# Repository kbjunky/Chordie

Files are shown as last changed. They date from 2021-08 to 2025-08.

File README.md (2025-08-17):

# **This project is deprecated, check back soon for an updated version of Chordie** #
# **Chordie**
## **A chording keyboard you shouldn't be scared of**

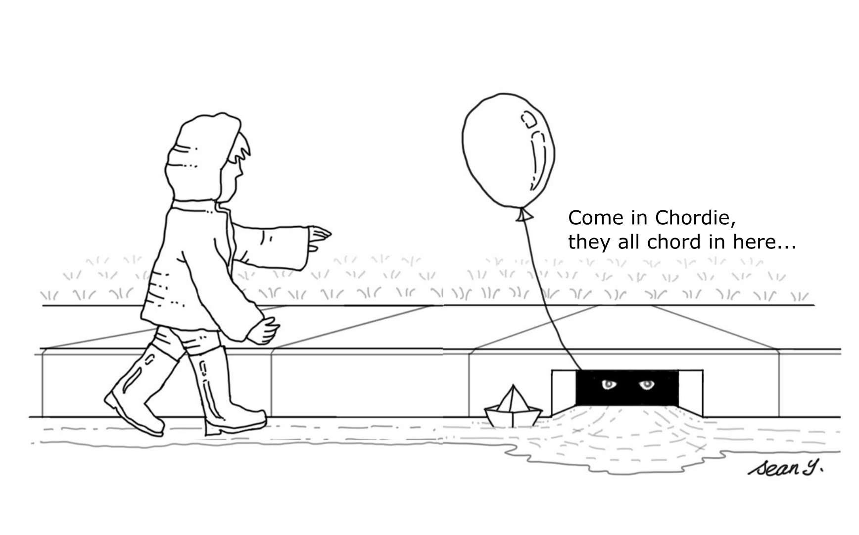
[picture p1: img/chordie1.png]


***Chordie "It" inspired picture courtesy of [Sean Yin](https://www.coroflot.com/sean_yin)***



### Chordie is a chording keyboard heavily inspired by [gBoards' Ginny keyboard](https://www.gboards.ca/product/ginni) running on awesome chording engine by [DennyTom](https://github.com/DennyTom/qmk_firmware/tree/feature/buttery_engine_v2/users/dennytom/chording_engine). It supports all 104 keys found on normal keyboards and much more in large part thanks to [ASETNIOP](http://asetniop.com/) layout. For a complete experience it's also equipped with trackball. Except for the mouse sensor module whole assembly can be handwired in about 6 hours.

## **BOM**
|Item |Count  |Example|
|:--- |:---:  |:---:|
|MCP23017 I2C Expander Breakout Board |2 |[Link](https://www.aliexpress.com/item/1005002491319987.html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)|
|Pro Micro 5V 16MHz |1 |[Link](https://www.aliexpress.com/item/32768308647.html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)|
|TRRS Socket PJ-320A |2 |[Link](https://www.aliexpress.com/item/4000661212458.html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)|
|TRRS Cable Male to Male 0.5m |1 |[Link](https://www.aliexpress.com/item/32905903526.html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)|
|Enameled copper wire 0.2mm 10m |1 |[Link](https://www.aliexpress.com/item/1005003799096513.html?spm=a2g0o.order_list.order_list_main.26.21ef18020rLkLI)|
|5mm kapton tape |1 |[Link](https://www.aliexpress.com/item/4000808659339.html?spm=a2g0o.order_list.order_list_main.86.21ef18020rLkLI)|
|EVQ-WGD001 encoder with switch |1 |[Link](https://www.aliexpress.com/item/4001293888953.html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)|
|Kailh Choc V1 25g or 20g MX switch |16 |[Link](https://www.aliexpress.com/item/4000907409650.html?spm=a2g0o.store_pc_groupList.8148356.11.606939a66Tvk6L)|
|Choc/MX keycaps 1u |10 |[Link](https://www.aliexpress.com/item/32979973961.html?spm=a2g0o.store_pc_groupList.8148356.21.1b9d36a4Coe1f0)|
|Choc/MX keycaps 1.5u |6 |[Link](https://www.aliexpress.com/item/4000135705283.html?spm=a2g0o.store_pc_groupList.8148356.31.5b1136a4d8gvZK)|
|8mm x 1mm antislip pads |14 |[Link](https://www.aliexpress.com/item/32767105328.html?spm=a2g0o.order_list.order_list_main.5.4f631802SBcIju)|
|ZrO2 bearing ball |3 |[Link](https://www.aliexpress.com/item/4000829132124.html?spm=a2g0o.order_list.order_list_main.24.649218029s2nlG)|
|M570/Ergo 34mm trackball ball |1 |[Link](https://www.aliexpress.com/item/1005003007477853.html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)|
|M2x3mm heat insert (optional) |15 |[Link](https://www.aliexpress.com/item/33021847966.html?spm=a2g0o.order_detail.order_detail_item.9.62d2f19cZBgXLP)
|M2x15mm screw (trackball) |3 |[Link](https://www.aliexpress.com/item/32973784147.html?spm=a2g0o.order_detail.order_detail_item.3.28ecf19cnWSpWO)
|M2x4mm screw |12 |[Link](https://www.aliexpress.com/item/32973784147.html?spm=a2g0o.order_detail.order_detail_item.3.28ecf19cnWSpWO)
|PMW3360 sensor module |1 |[Link](https://github.com/kbjunky/PMW3360) \| [Link](https://www.aliexpress.com/item/1005007729769668.html?spm=a2g0o.order_list.order_list_main.55.649218029s2nlG)

## **IrDA** ***(optional)***
|Item |Count  |Example|
|:--- |:---:  |:---:|
|TCRT5000 sensor |2 |[Link](https://www.aliexpress.com/item/32841920225.html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)|
|680/10k Ohm resistor |2 each |[Link](https://www.aliexpress.com/item/32847096736.html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)

## **Tools**
|Item |Count  |Example|
|:--- |:---:  |:---:|
|Soldering iron 80W |1 |[Link](https://www.aliexpress.com/item/4000005873814.html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)|
|Tin wire 0.5 to 1mm will do |1 |[Link](https://www.aliexpress.com/item/32946643268.html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)|
|Hot glue gun (optional) |1 |[Link](https://www.aliexpress.com/item/1005001393578323.html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)|
|Solder flux/paste |1 |[Link](https://www.aliexpress.com/item/32948598235.html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)
|Digital multimeter with diode test |1 |[Link](https://www.aliexpress.com/item/1005004951791846.html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)

## **Remarks**
*   You can buy a bundle that is soldering iron + tin wire + some other accessories that you think might come usefull. Buying a bundle with a multimeter is a good idea.
*   Better kecaps are [MKUltra](https://mkultra.click/mbk-choc-keycaps).
*   For MX switches any linear switch can be swapped with 20g spring.
*   TRRS cable can be L shaped only on the left side due to the trackball blocking the way on the right side.
*   Solder flux helps with melting isolation on the enameled wire. Just put some where you need to melt the isolation and it should melt quickier.
*   Multimeter (continuity tester) is a must and comes handy when testing if every wire is connected properly.
*   Using heat inserts is recommended.

# **Build guide**

## **Chordie OpenSCAD generator**
Chordie comes with OpenSCAD generator that allows for easy cutomization of:
*   Height of switch/encoder columns.
*   Use of heat inserts or just screws.
*   I2C expander mounting hole dimensions as well as having expander exposed/covered.
*   Choc/MX type sockets.
*   IR sensor.
*   Custom tolerance of switch/encoder sockets.

How to customize your Chordie:
*   Download and install [OpenSCAD](https://openscad.org/).
*   Open ***config.scad*** from generator folder of this repository with OpenSCAD.
*   Adjust settings following tips from the config file.
*   When ready to print hit 'Render' (F6) and then ***File->Export to STL***.
*   Tip: Encoder (ENC) column should be a bit higher than (FF) column. Also thumb keys should be a bit higher than the rest. But this is mostly my preference. 
*   Tip: When measuring I2C expander boards provide exact value into the config file. Proper margin will be added by default.



## **3D printing**
Recommended settings:
*   Material: any, preferably PLA/PETG
*   Layer height 0.2mm
*   Infill >=15%
*   Supports are needed under audio jack holes and on the trackball where MCU USB socket is placed.

## **Wiring**
Before you start make sure your Chordie suits your hands well. Play with it for a while with just switches placed into the sockets. Wiring takes some time and last thing you want to do is to start over because some part isn't properly setup. For example you might find out that encoder is too low etc. Check if canals for the wires aren't filled with plastic. Check if all parts (switches/audio jacks/encoder/I2C exapanders etc.) fit into their sockets.

**While routing check every connection with continuity meter!**

**If you're using heat inserts start with them. Once done try if the bottom plate fits etc.**
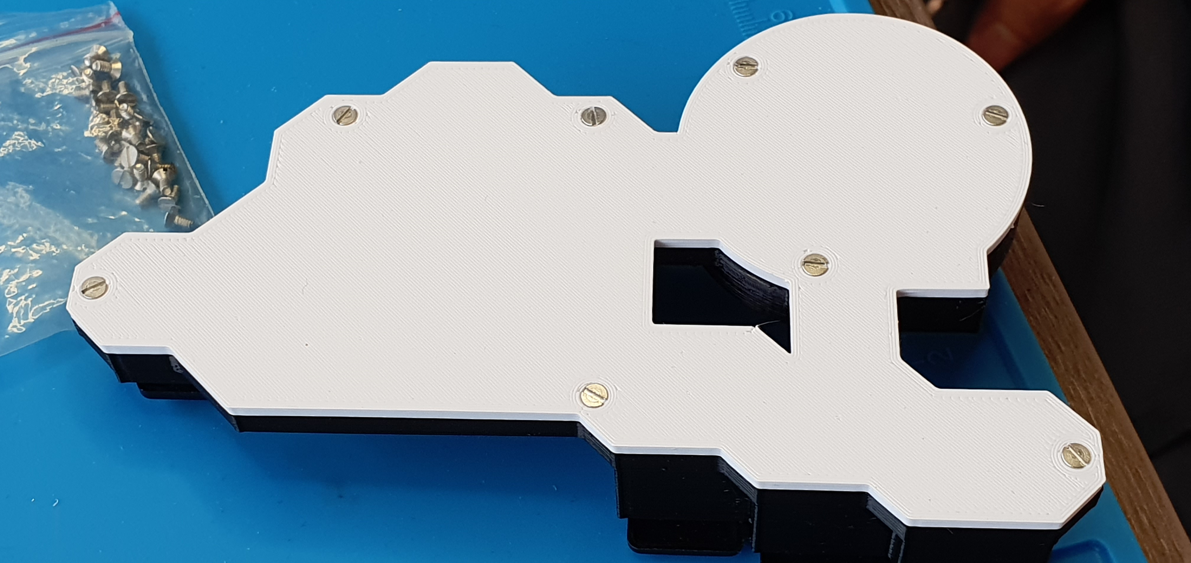
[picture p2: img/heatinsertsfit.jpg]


Attach kepton tape to the bottom side of ProMicro and top side of I2C expanders(cover the pads). This way you will avoid tin blobs.


Setup the address pins on I2C expanders following the diagram.

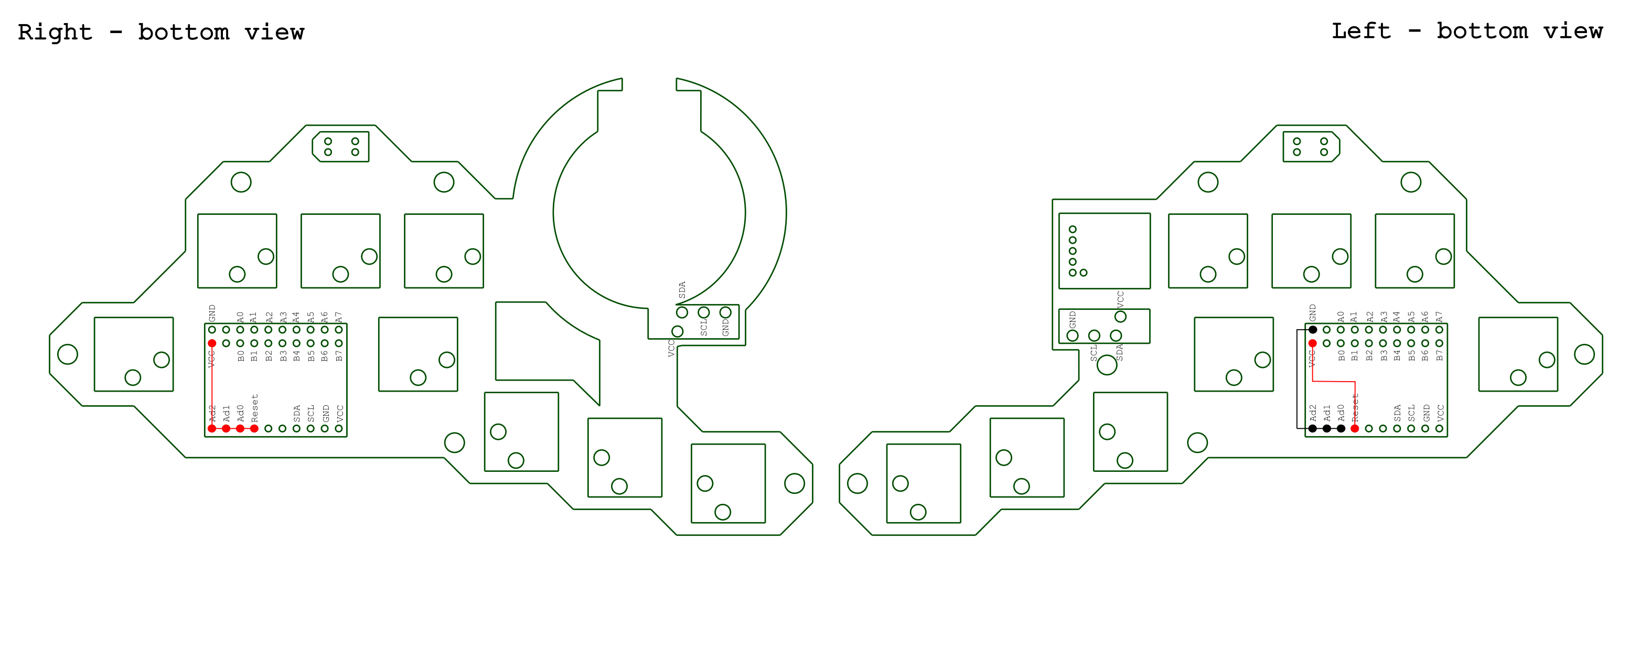
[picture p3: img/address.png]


It should look something like this.



Next you will have to prepare the switches. Put some tin on every switch pin then place the switches into the sockets. Make sure pins are facing the same way as on the photo/diagram. At this point you can also attach the I2C expander. Use small amount of hot glue to lock it in place. Be sure not to cover any of the pads.

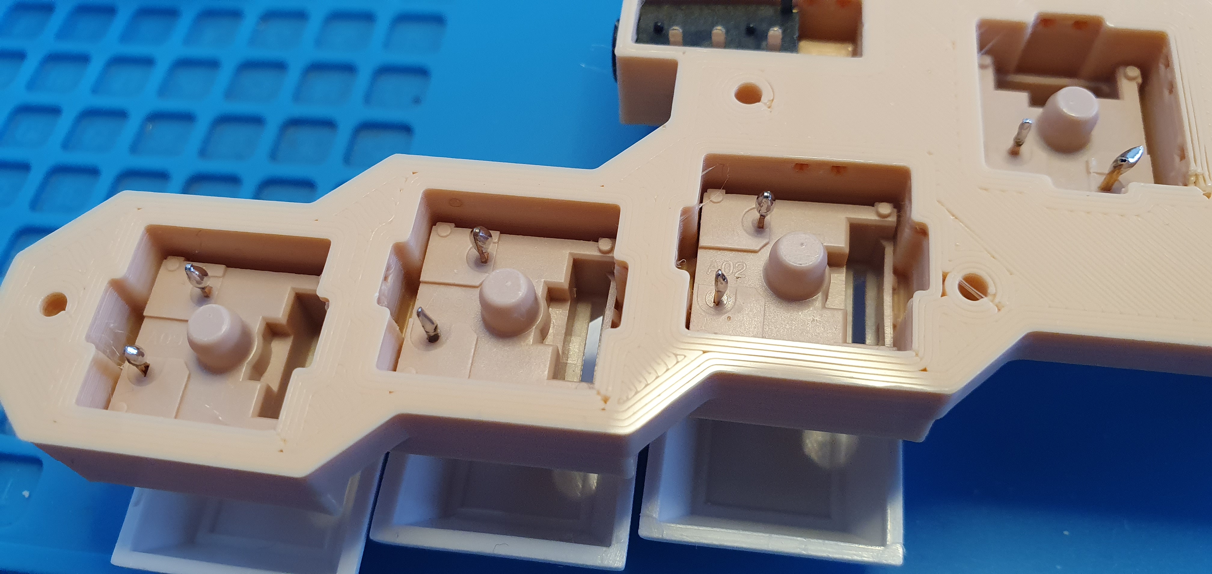
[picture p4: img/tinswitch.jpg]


Once this is done follow the below diagram and connect all the GND pins for the switches. For now skip the rotary encoder/audio jack part. These will be done later. Route the enameled wire through the canals. For this part use one wire that will connect every switch GND pin and then connect to the nearest GND on the I2C Expander.

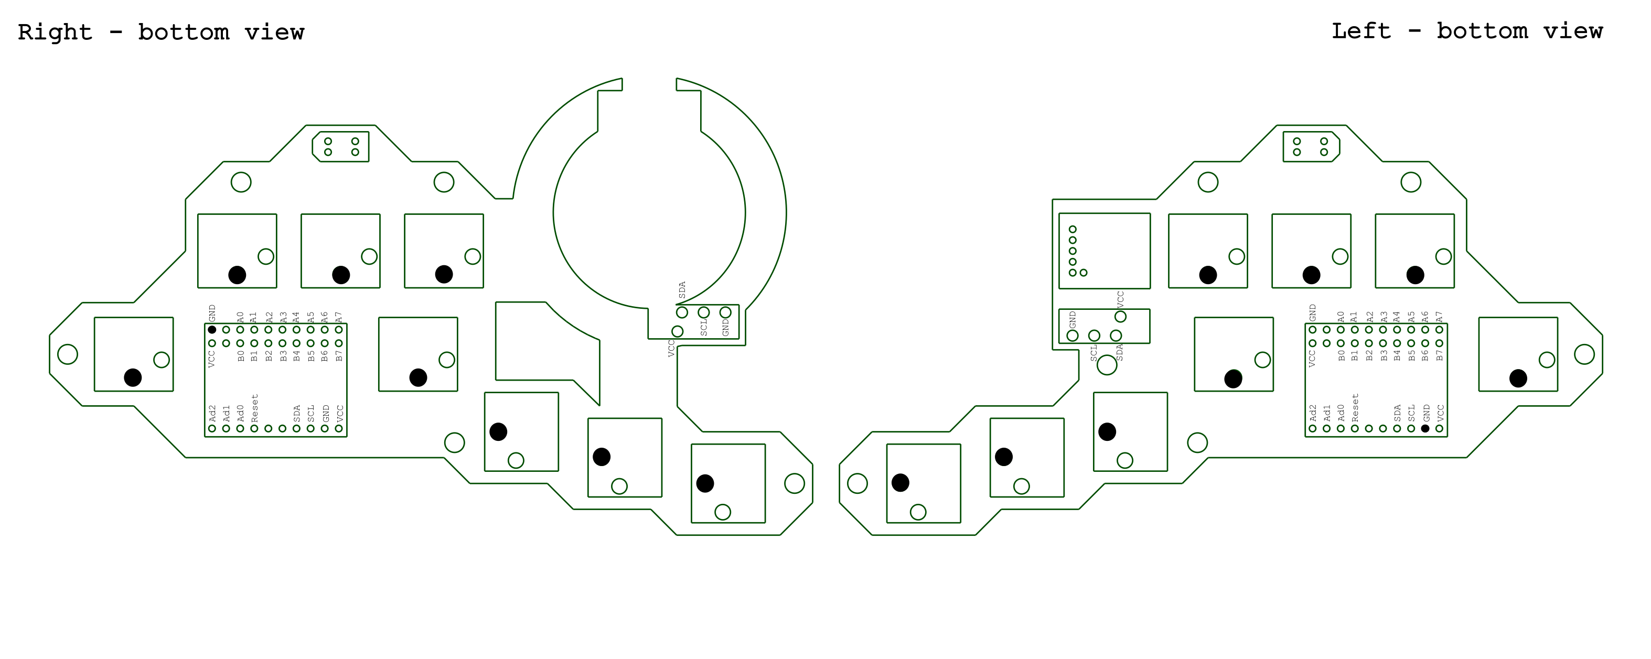
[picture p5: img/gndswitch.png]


It should look more or less like this (don't mind the encoder and audio jack, it's not important at this stage).

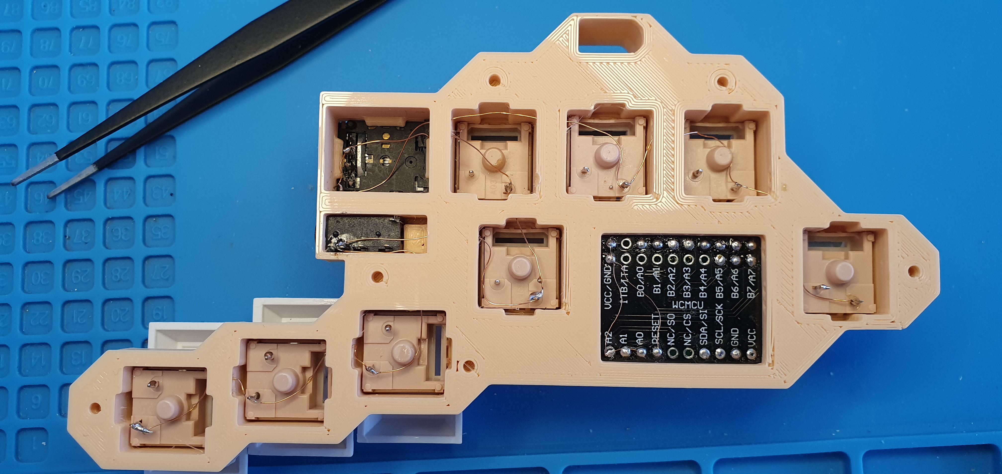
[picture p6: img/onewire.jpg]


Now you can move to connecting switches to the I2C Expander. Refer to the diagram. **Avoid routing over 'B' pads on I2C Expander. Check the photo below on how to properly route the wires.** 

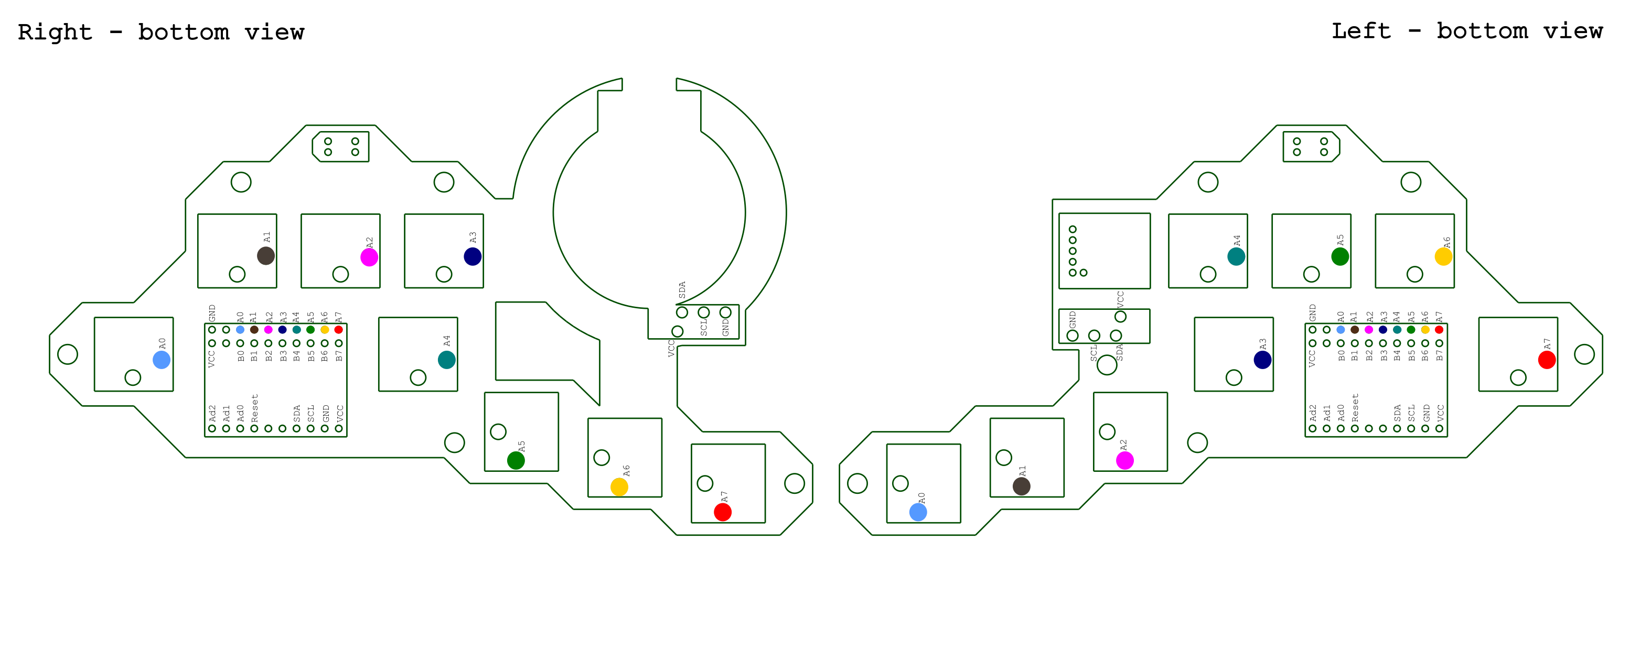
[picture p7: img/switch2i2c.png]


Wiring should look like this. Note how wires mostly go up, it's OK even if it means goind around.

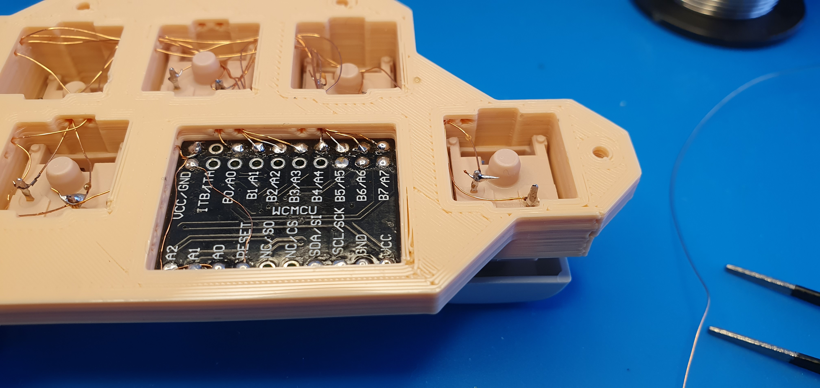
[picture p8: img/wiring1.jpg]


Now it's time to connect the encoder. Attach long pieces of wire to it's pins. There are 2 pins that are GND (refer to the diagram). Connect them with one long wire. When routing, those GND pins can be connected to any nearest GND either to a switch or just directly to the wire.

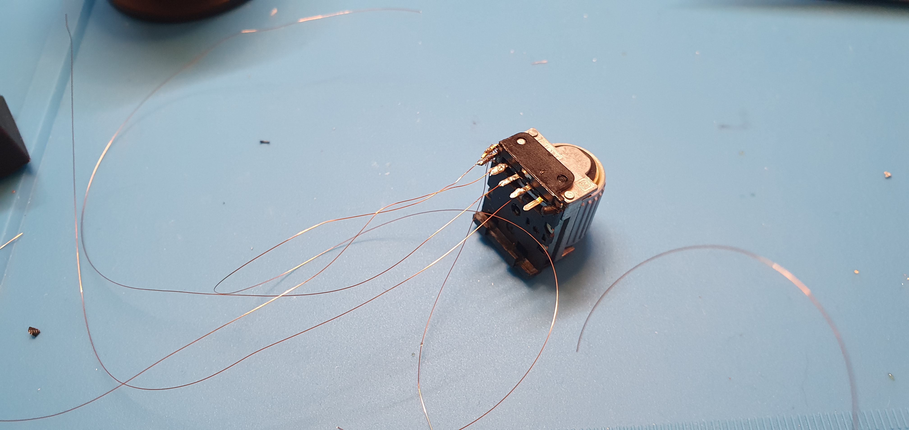
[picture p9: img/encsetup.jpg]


Refer to the diagram when connecting encoder to the I2C Exapnder.
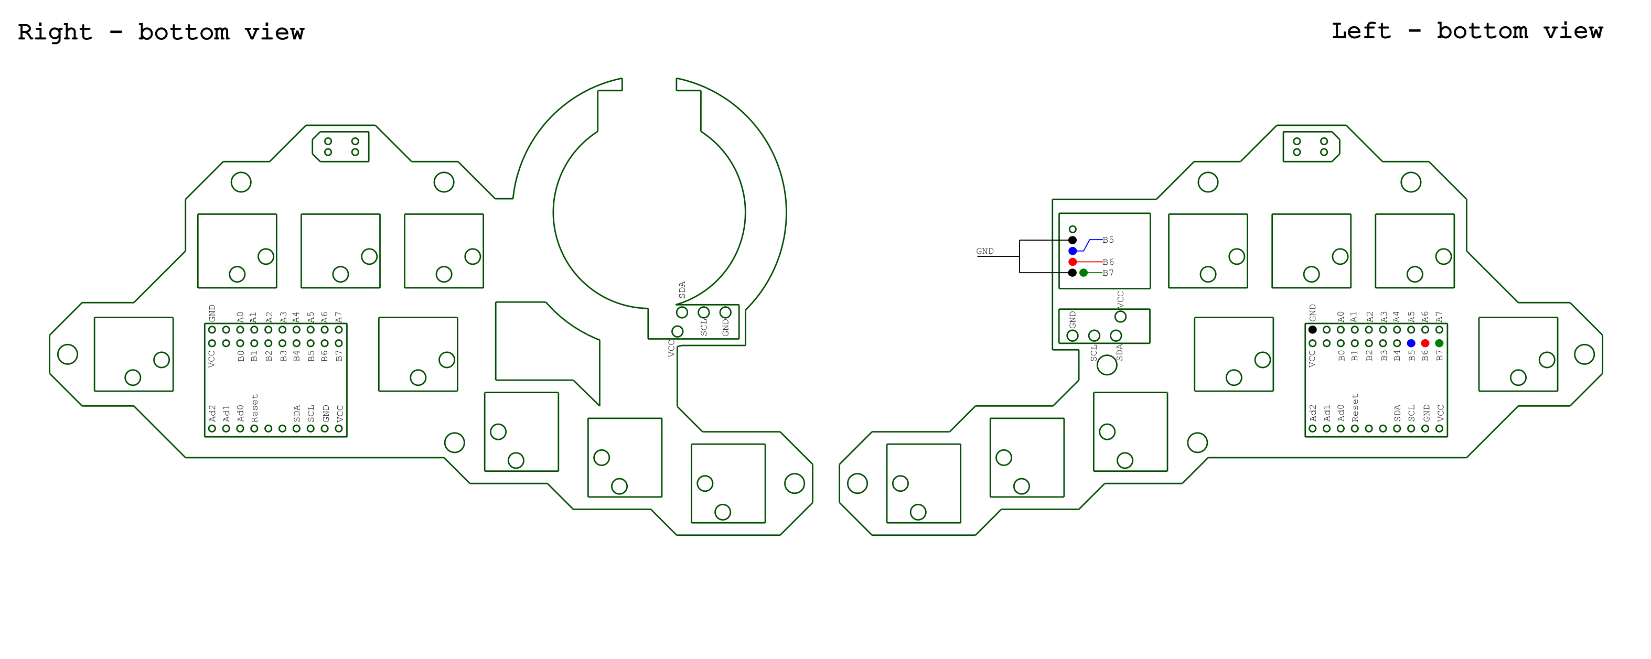
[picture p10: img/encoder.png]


Now it's time for audio jacks. They should fit quite tight. Use some tool to push them inside. Use the 3D printed spacers to prevent sockets from sliding out when connecting the TRRS cable.



Now follow the diagram and connect all pins accordingly. Routing start from I2C Expander towards the audio socket and then leave some wire that will later on be connected to Pro Micro. It's easier this way compared to later on trying to solder additional wire to the audio socket pin.

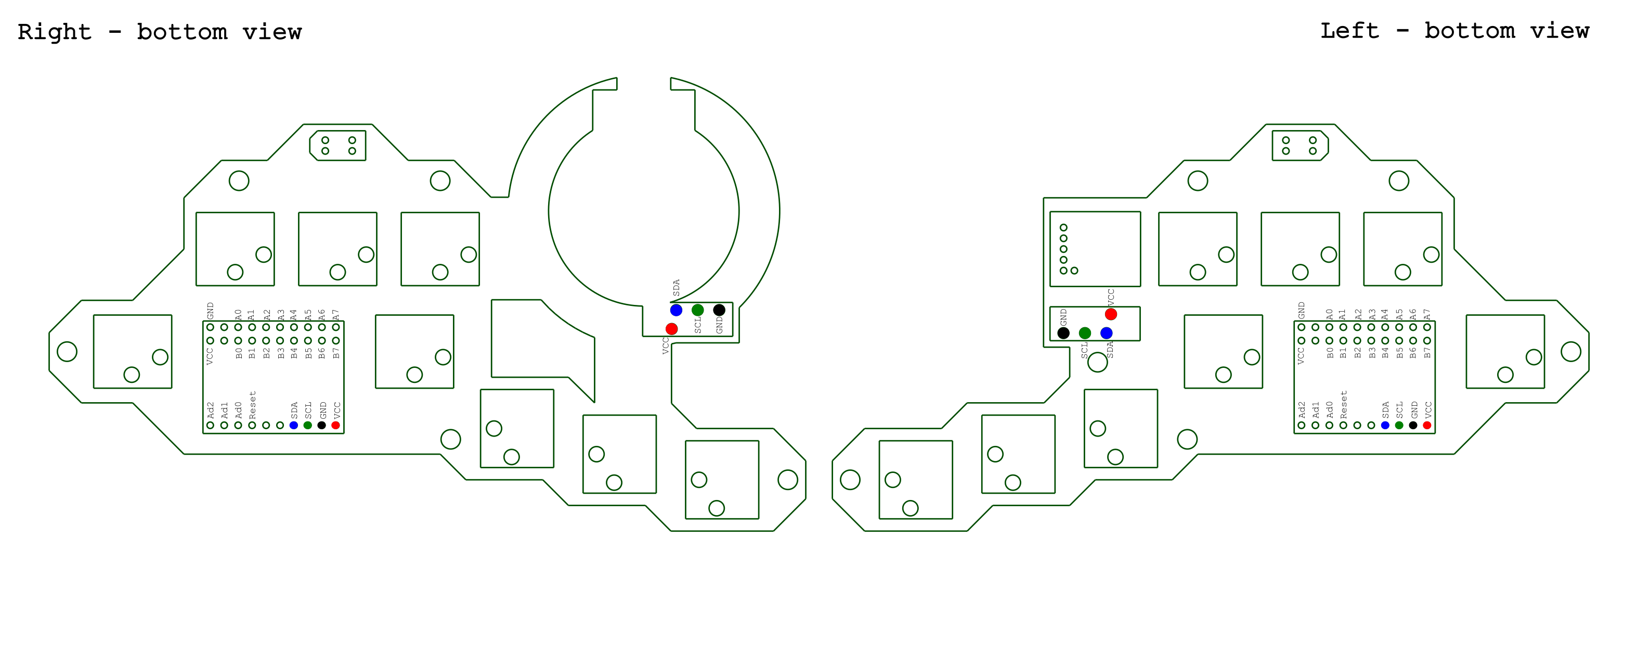
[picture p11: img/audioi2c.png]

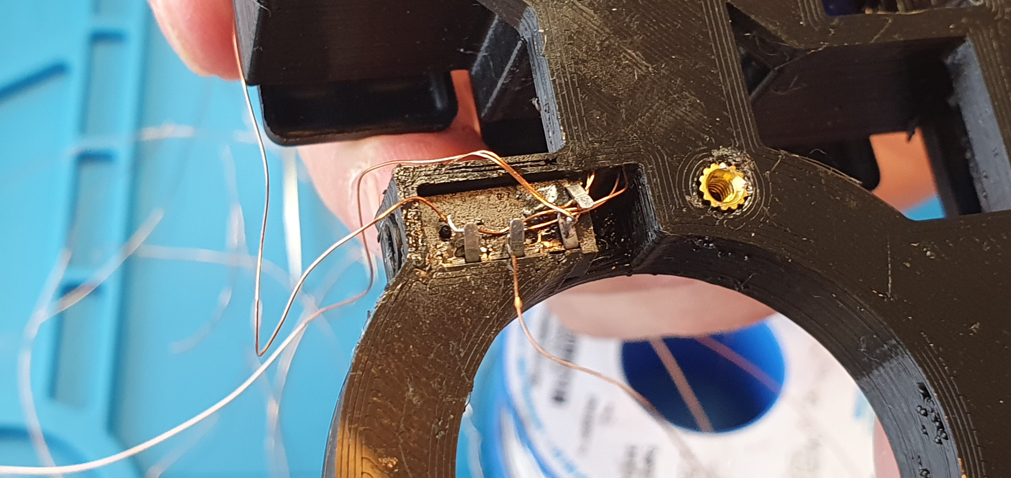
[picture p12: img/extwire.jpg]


If you've decided on using IrDA here's how it should be wired.

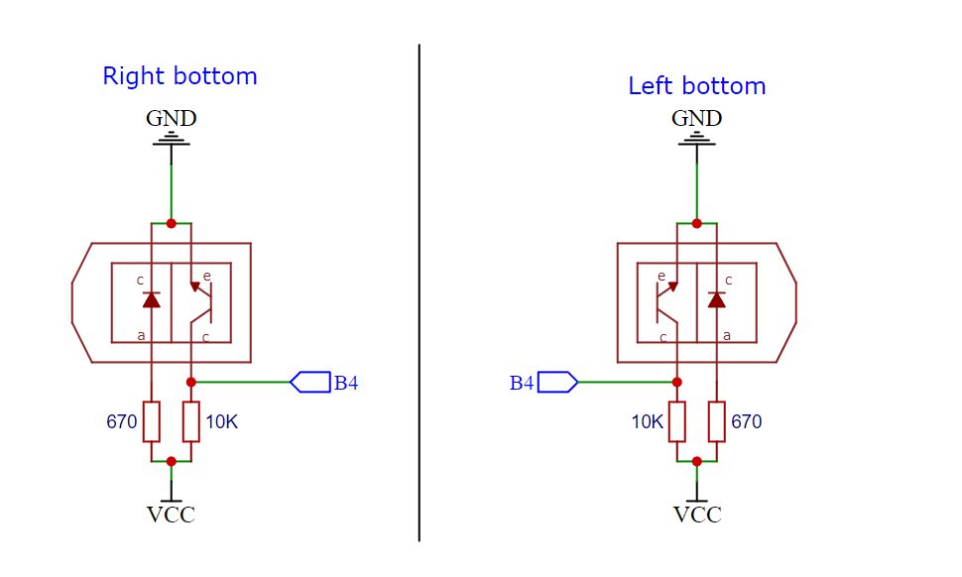
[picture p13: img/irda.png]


At this point you should have a working mouse sensor and be able to connect it to the ProMicro as well as connecting SDA (ProMicro pin 2)/SCL (ProMicro pin 3)/VCC/GND lines from the keyboard to the ProMicro. For connecting sensor to the ProMicro you can use the same enameled wire. Sandwich it with the ProMicro. There's a dedicated space for ProMicro on the bottom plate to hold it in place, in between the studs that hold mouse sensor. 

## **Mouse sensor wiring**
|ProMicro Pin|Sensor pin|
|:--- |:---:|
|A0 |NCS  |
|15 |SCLK |
|14 |MISO |
|16 |MOSI | 

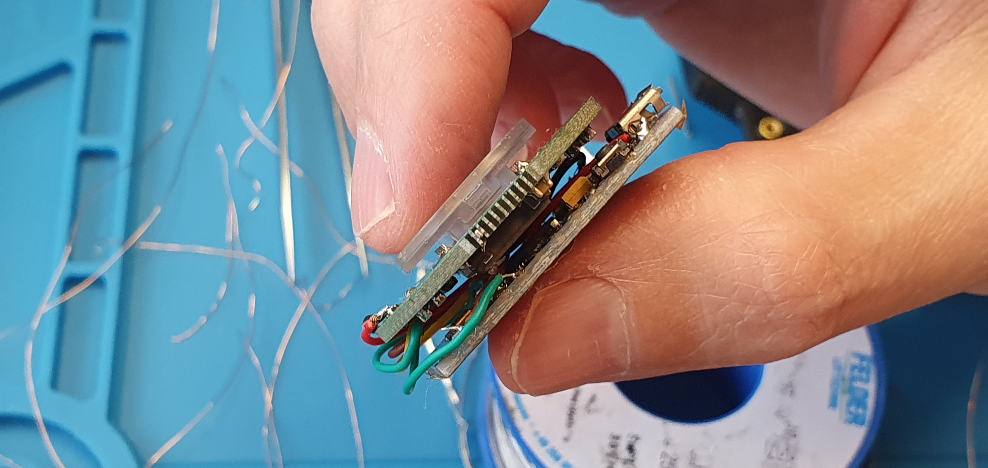
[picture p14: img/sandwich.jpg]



Congratulations!

Now it's flashing time, check **src** folder for flashing/layout information.

**And that's it. Congratulations!**

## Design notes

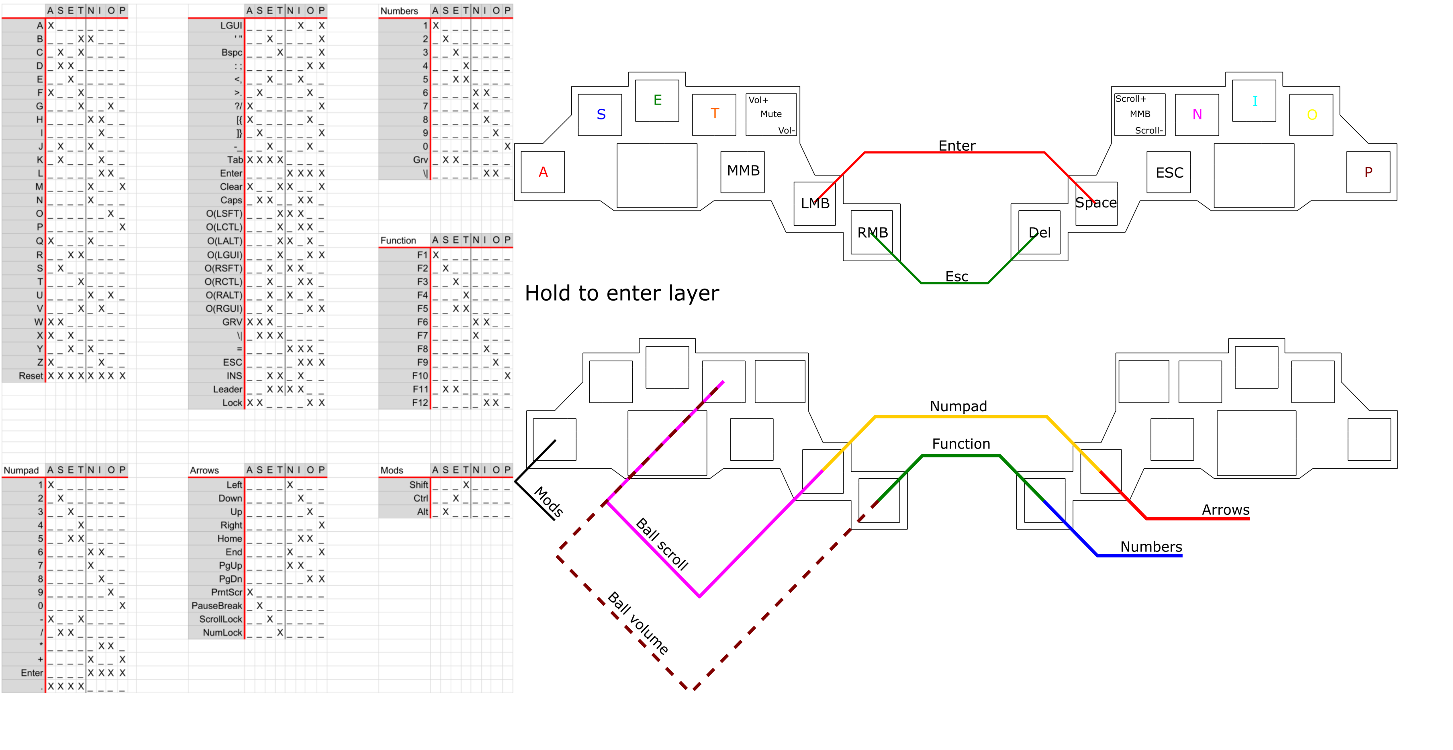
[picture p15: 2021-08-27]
img/keymap1.png

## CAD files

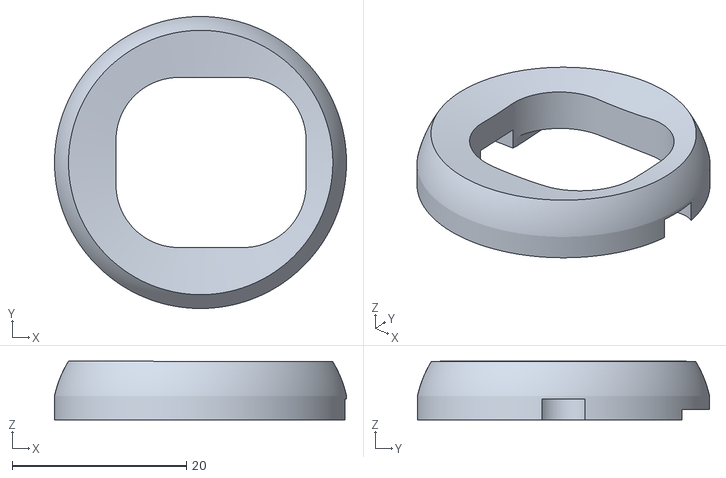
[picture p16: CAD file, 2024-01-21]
stl/bearing_trap.stl
33.5 x 33.5 x 6.75

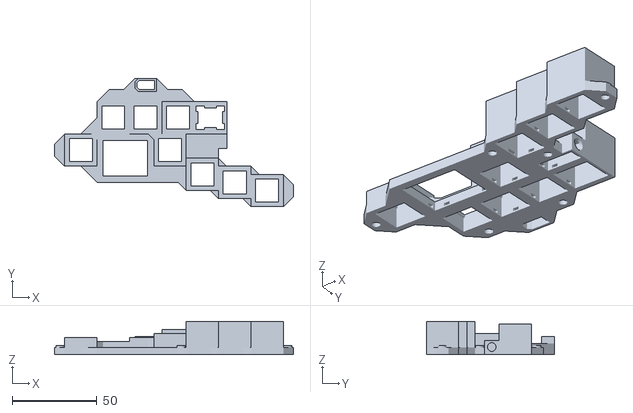
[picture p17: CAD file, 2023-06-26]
stl/default_choc_left.stl
140.6 x 75.6 x 19.5

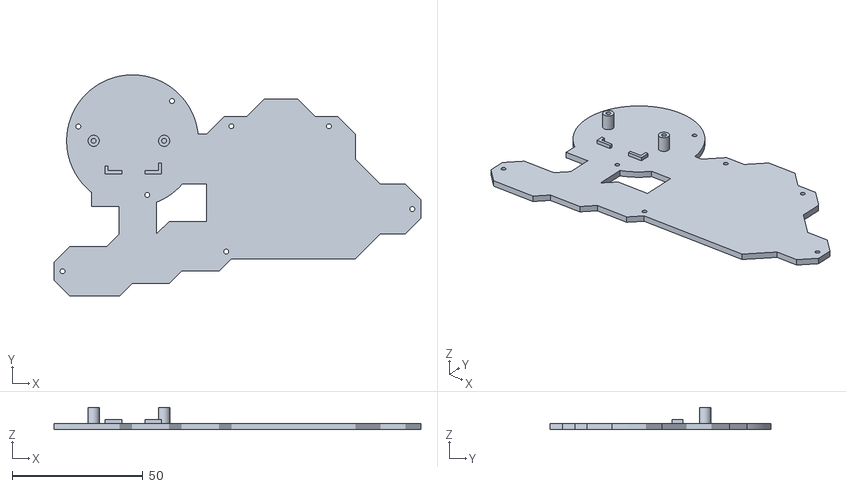
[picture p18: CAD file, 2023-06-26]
stl/bottom_right.stl
140.6 x 84.7 x 8.45

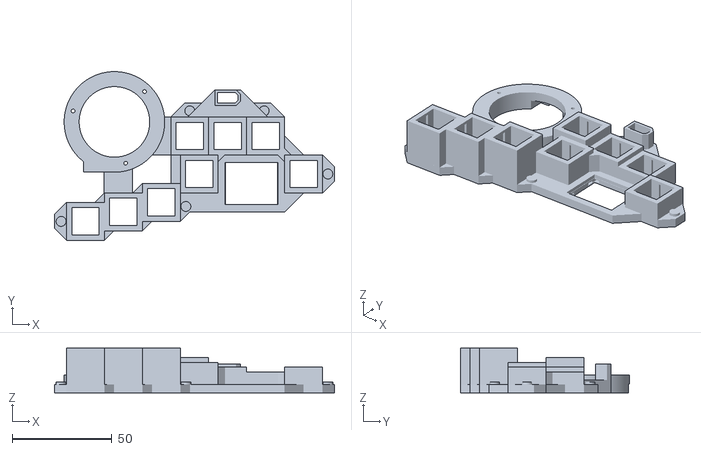
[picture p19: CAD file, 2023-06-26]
stl/default_mx_right.stl
140.6 x 84.8 x 22.5

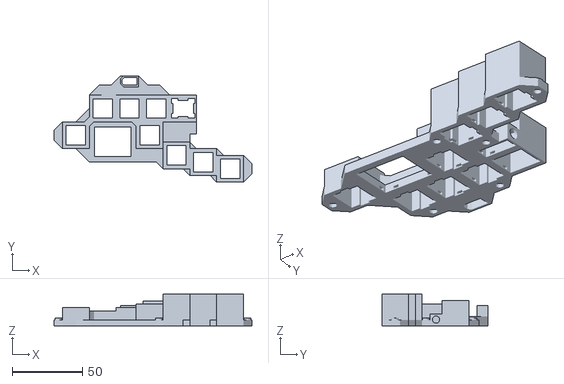
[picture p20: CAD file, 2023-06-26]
stl/default_mx_left.stl
140.6 x 75.6 x 22.5

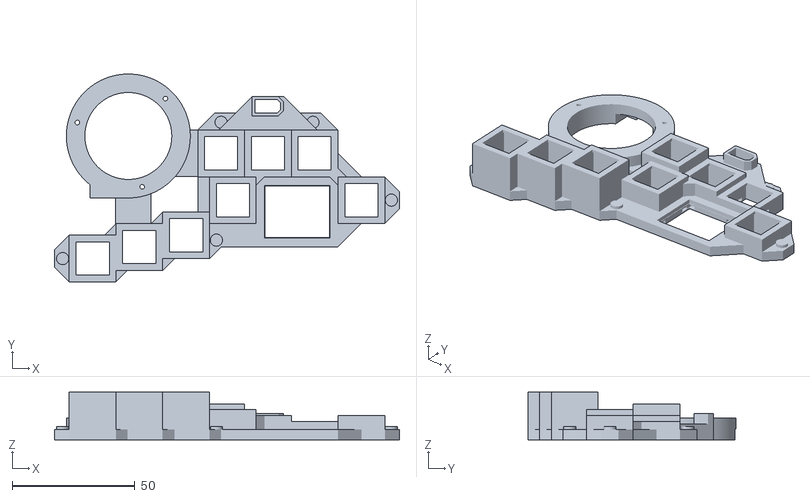
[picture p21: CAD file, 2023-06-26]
stl/default_choc_right.stl
140.6 x 84.8 x 19.5

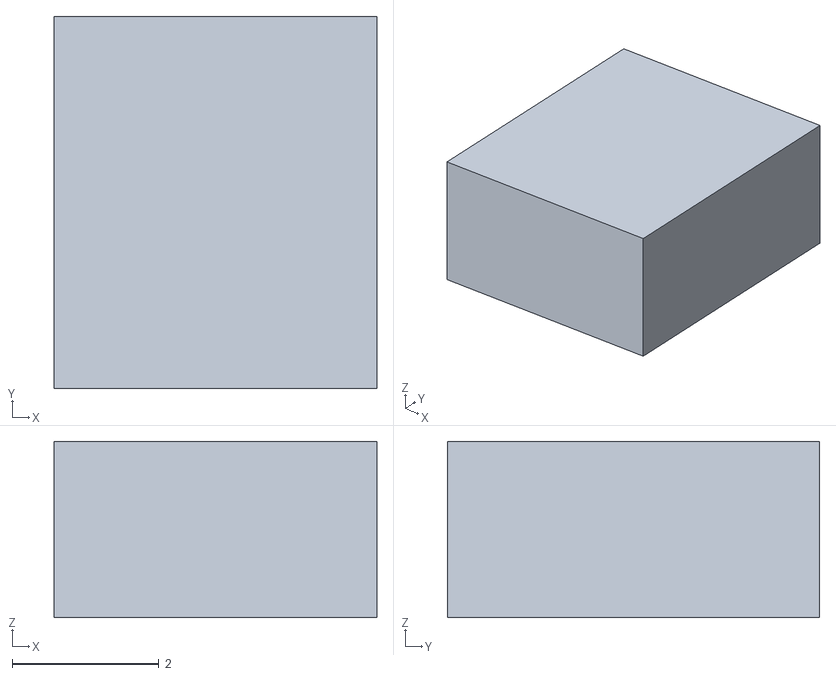
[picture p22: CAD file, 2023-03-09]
stl/audiojack_lock.stl
4.40 x 5.07 x 2.40

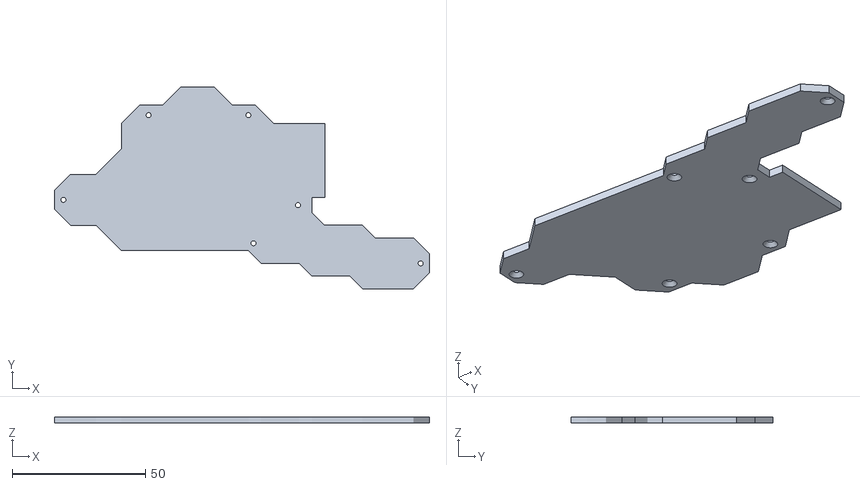
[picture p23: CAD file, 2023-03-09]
stl/bottom_left.stl
140.6 x 75.6 x 2.40

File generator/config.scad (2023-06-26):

/*
    Set your I2C expander dimensions, provide exact values measured. Tolerance will be added automatically
*/
EXPANDER_WIDTH = 26.6;
EXPANDER_DEPTH = 21.3;
EXPANDER_EXPOSED = true;

/*
    Z position of individual keys. 1.0 = 19.05mm. Use 0.25 step ie. 0.25, 0.5, 0.75, 2.5, 2.75 etc.

                | ENC | TN | EI | SO |
                | TB1 | FF |         | AP |
          | TB2 |
    | TB3 |

*/
TB3_Z = 0.75;    
TB2_Z = 0.75;
TB1_Z = 0.75;
FF_Z = 0.375;
TN_Z = 0.5;
EI_Z = 0.25;
SO_Z = 0.125;
AP_Z = 0.25;
ENC_Z = 0.625;

/* 
    If true will generate right side with trackball etc. otherwise left side with encoder
*/
RIGHT_SIDE = false; 

/*
    Type of socket to generate. "choc" for Choc or "mx" for MX compatible socket
*/
GENERATE = "choc";

/*
    Generate holes for heat inserts?If false then M2 screw
*/
HEAT_INSERTS = true;

/* 
    Proximity sensor
*/
IR_SENSOR = true;

/* 
    Socket tolerance, change to make sockets tighter/more lose
*/
SOCKET_TOLERANCE = -0.11;

/*
    Encoder socket tolerance, only for horizontal encoder
*/
ENCODER_SOCKET_TOLERANCE = 0;


include <chordie.scad>

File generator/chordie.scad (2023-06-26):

GRID_SIZE = 19.05;  //Socket outer size

CHOC_SOCKET = [["type", "choc"], ["height", 5.2]];
MX_SOCKET = [["type", "mx"], ["height", 8.2]];
ENC_SOCKET = [["type", "encoder"], ["height", 6]];
BASEPLATE = [["height", 4.2]];
EXPANDER = [["width", EXPANDER_WIDTH+expander_tolerance()], ["depth", EXPANDER_DEPTH+expander_tolerance()], ["position", [83.38, 1*GRID_SIZE, 0]]];
PROXIMITY_SENSOR = [["position", [71.44, 62.09, 0]]];

SOCKET = (GENERATE == "mx") ? MX_SOCKET : CHOC_SOCKET;

function TranslateSwitch(x, y, z) = [x*GRID_SIZE, y*GRID_SIZE, z*GRID_SIZE];    //Translate switch according to grid
function setup_generator(socket_type) = socket_type == "mx" ? MX_SOCKET : CHOC_SOCKET;
function lor(con, lval, rval) = (con) ? lval : rval; // "left or right", depending on which side is generated will return different value
function expander_tolerance() = lor(EXPANDER_EXPOSED, 0.1, 0.2);

//helper functions for managing lists, parameter extraction etc
function is_in(set, value) = set[0]==value ? true : false;
function tail(set) = len(set) >1 ? [for(i=[1:1:len(set)-1]) set[i]] : undef;
function head(set) = is_list(set) ? set[0] : undef;
function get(set, value) = set == undef ? undef : is_in(head(set), value) ? head(set)[1] : get(tail(set), value); 

function type_of(set) = get(set, "type");   

function position_of(set) = get(set, "position");   
function rotation_of(set) = get(set, "rotation");   

function height_of(set) = get(set, "height");    
function depth_of(set) = get(set, "depth");
function width_of(set) = get(set, "width");


switch_placement = [
    [   //TB3
        ["position", TranslateSwitch(0,0,TB3_Z)],
        ["rotation", [0,0,90]],
        ["type", type_of(SOCKET)]
    ],
    [   //TB2
        ["position", TranslateSwitch(1,0.25,TB2_Z)],
        ["rotation", [0,0,90]],
        ["type", type_of(SOCKET)]
    ],
    [   //TB1
        ["position", TranslateSwitch(2,0.5,TB1_Z)],
        ["rotation", [0,0,90]],
        ["type", type_of(SOCKET)]
    ],
    [   //FF
        ["position", TranslateSwitch(3,1.25,FF_Z)],
        ["rotation", [0,0,0]],
        ["type", type_of(SOCKET)]
    ],
    [   //AN
        ["position", TranslateSwitch(2.75,2.25,TN_Z)],
        ["rotation", [0,0,0]],
        ["type", type_of(SOCKET)]
    ],
    [   //SI
        ["position", TranslateSwitch(3.75,2.25,EI_Z)],
        ["rotation", [0,0,0]],
        ["type", type_of(SOCKET)]
    ],
    [   //EO
        ["position", TranslateSwitch(4.75,2.25,SO_Z)],
        ["rotation", [0,0,0]],
        ["type", type_of(SOCKET)]
    ],
    [   //TP
        ["position", TranslateSwitch(5.75,1.25,AP_Z)],
        ["rotation", [0,0,0]],
        ["type", type_of(SOCKET)]
    ],
    [
        //ENC
        ["position", TranslateSwitch(1.75, 2.25, ENC_Z)],
        ["rotation", [0,0,0]],
        ["type", type_of(ENC_SOCKET)]
    ]
];

baseplate_polygon = [
    [-9.53, -9.53],
    [9.53,  -9.53],
    [14.29, -4.76],
    [28.58, -4.76],
    [33.34, 0],
    [47.63, 0],
    [52.39, 4.76],
    [100.01, 4.76],
    [109.54, 14.29],
    [119.06, 14.29],
    [125.06, 20.29],
    [125.06, 27.34],
    [119.06, 33.34],
    [109.54, 33.34],
    [100.01, 42.86],
    [100.01, 52.39],
    [93.06, 59.34],
    [84.52, 59.34],
    [77.82, 66.04],
    [65.05, 66.04],
    [58.35, 59.34],
    [49.81, 59.34],
    [42.86, 52.39],
    [42.86, 19.05],
    [28.57, 19.05],
    [23.81, 14.29],
    [9.52, 14.29],
    [4.76, 9.53],
    [-9.53, 9.53],
    [-15.53, 3.53],
    [-15.53, -3.53]  
];

proximity_sensor_polygon = [
    [-5.19, -2.75],
    [3.76, -2.75],
    [5.19, -1.32],
    [5.19, 1.32],
    [3.76, 2.75],
    [-5.19, 2.75]
];

proximity_sensor_base_polygon = [
    [50.42, 51.4],
    [92.46, 51.4],
    [77.82, 66.04],
    [65.05, 66.04],
];

encoder_cap_polygon = [
    [67.47, 8.54],
    [70.04, 5.96],
    [96.72, 5.96],
    [99.21, 8.45],
    [99.21, 29.64],
    [96.31, 32.54],
    [70.44, 32.54],
    [67.47, 29.57]
];

audio_socket_base_polygon = [
    [42.96, 18.95],
    [28.58, 18.95],
    [28.57, 24.64],
    [23.71, 24.64],
    [23.71, 33.44],
    [42.96, 33.44]
];

heat_insert_holes = [
    ["common", [[-12.21,0], [50.44, 7.52], [121.73, 23.81], [89.77, 55.55], [52.39, 55.55]]],
    ["left", [[33.77, 21.84]]],
    ["right", [[20.2, 29.25], [29.68, 65.21], [-6.2, 55.45]]]
];

module baseplate_extrude() {
    linear_extrude(height_of(BASEPLATE))   
        polygon(baseplate_polygon);
}

module proximity_sensor_extrude() {
    translate(position_of(PROXIMITY_SENSOR)+[0,0,-0.01])            
    linear_extrude(height_of(BASEPLATE)+height_of(SOCKET)+lor(type_of(SOCKET)=="mx",6, 1.2)+EI_Z*height_of(SOCKET))
        polygon(proximity_sensor_polygon);   
}

module proximity_sensor_base_extrude() { 
    linear_extrude(height_of(BASEPLATE)+min([SO_Z, EI_Z, TN_Z])*GRID_SIZE)
        polygon(proximity_sensor_base_polygon);
}

module encoder_cap_extrude () {
    linear_extrude(height_of(CHOC_SOCKET))
        polygon(encoder_cap_polygon);
}

module audio_socket_base_extrude() {
    linear_extrude(height_of(BASEPLATE))
        polygon(audio_socket_base_polygon);
}

module ProximitySensorSocket() {
    let(
        wall_thickness = 1.2
    ) {
        translate(position_of(PROXIMITY_SENSOR))
        linear_extrude(height_of(BASEPLATE)+height_of(SOCKET)+EI_Z*height_of(SOCKET))
            offset(delta=wall_thickness)
                polygon(proximity_sensor_polygon);
    }
}
module EncoderSupport(w, r=[-90,0,0]){
    translate([0,-w/2,0])
    rotate(r)
    linear_extrude(w)
        polygon([[0,0], [1.201,0], [1.2,2.4]]);
}

module SocketEncoder(position, rotation) {
    let(
        enc_width = GRID_SIZE + 0.2,
        enc_depth = GRID_SIZE,
        cut_width = 16.8+ENCODER_SOCKET_TOLERANCE,
        cut_depth = 13.9+ENCODER_SOCKET_TOLERANCE,
        support_lenght = 7
    ){
        translate([position.x, position.y, position.z]){
            rotate(rotation){
                translate([0,0,height_of(ENC_SOCKET)/2])
                difference(){
                    cube([enc_width, enc_depth, height_of(ENC_SOCKET)], true);
                    cube([cut_width, cut_depth, height_of(ENC_SOCKET)+4], true);
                }
                
                //Bottom
                mirror([0,1,0])
                translate([0,cut_depth/2,0])
                rotate([0,0,90])
                translate([-1.199,0,height_of(ENC_SOCKET)-1.3])
                    EncoderSupport(support_lenght);

                //Top
                translate([0,cut_depth/2,0])
                rotate([0,0,90])
                translate([-1.199,0,height_of(ENC_SOCKET)-1.3])
                    EncoderSupport(support_lenght);
                
                //Left
                mirror([1,0,0])
                translate([cut_width/2-1.2,0,height_of(ENC_SOCKET)-1.3])
                    EncoderSupport(support_lenght);
                
                //Right
                translate([cut_width/2-1.2,0,height_of(ENC_SOCKET)-3.6])
                    EncoderSupport(support_lenght);        
                       
            }
        }
        //Column under the socket
        translate([position.x, position.y, position.z/2])
            rotate(rotation)
                difference(){
                    cube([enc_width+0.001, enc_depth+0.001, position.z], true);
                    cube([cut_width, cut_depth, position.z + 0.05], true);  
                }    
        }
}
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

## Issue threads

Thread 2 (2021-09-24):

how to flash

Mar-Shayal, 2021-09-24:
I'm really excited about this project, but I have no idea how to flash/customize the board after I assemble it. My only experience is with QMK (online configurator). I see all the code in the src folder, but I don't even know if I am supposed to use a local QMK build environment for that (not that I actually know how). Can anyone help me out, or at least point me in the right direction? This board is elite level, but I don't want to be scared of Chordie. Thanks so much!

kbjunky, 2021-09-24:
No need to be scared. Just follow [ QMK guide](https://docs.qmk.fm/#/newbs_getting_started) to setup the environment and it should be easy from there. Hit me up on Reddit /u/kbjunky and I can send you compiled hex but if you're planning on doing any modifications I would suggest setting up the environment.

Mar-Shayal, 2021-09-24:
Thank you! I didn't realize it used the QMK environment, so that's a relief even though it's going to be a bit of a learning curve. Let me see how I make out.

Chordie is literally the coolest looking keyboard ever made, I'm really looking forward to seeing the finished product!

Closed 2025-08-14.

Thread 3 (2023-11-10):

keyboard-only build

drlkf, 2023-11-10:
Hello!
I'm currently doing a keyboard-only build (10 keys, no trackball, no rotary encoder), and I'm not quite sure how to finish my build, all the instructions to plug the ProMicro are related to the trackball sensor and the rotary encoder, so I don't know how I'm supposed to link mine to one of the expanders, I'm actually perplex as to whether or not I need the ProMicro at all, but I don't see how to plug the keyboard to the computer without it so I'm guessing it's necessary. Could you enlighten me?
Thanks!

kbjunky, 2023-11-11:
On the left side you have to connect switches to the expander as per instruction and then SDA/SCL/VCC/GND from the expander to the audio jack socket. On the right side you do  the same and then also SDA/SCL/VCC/GND to the corresponding pins on the ProMicro.

drlkf, 2023-11-11:
Great, thanks!

Closed 2023-11-11.

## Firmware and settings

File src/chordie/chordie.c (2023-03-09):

#include "chordie.h"

#define HIGH 0b11111111
#define LOW 0

#define SCROLLV_TRESHOLD 8
#define SCROLLH_TRESHOLD 8
#define VOLUME_TRESHOLD 16
#define BALL_SCROLL 5
#define BALL_VOLUME (BALL_SCROLL + 1)

static i2c_status_t last_err = 0;
bool i2c_initialized = false;

int8_t scrollv=0;
int8_t scrollh=0;

extern uint8_t current_pseudolayer;

void i2c_initialize(void){
    dprint("I2C init start\n");
    if(!i2c_initialized) {
        i2c_init();
        i2c_initialized = true;
        
    }

    //1st device
    //set A as outputs
    i2c_write8(I2CR_ADDRESS, IODIRA, HIGH);
    i2c_write8(I2CR_ADDRESS, IODIRB, HIGH);
    //seems like A pull ups also needed
    i2c_write8(I2CR_ADDRESS, GPPUA, HIGH);
    //set B pull ups ON
    i2c_write8(I2CR_ADDRESS, GPPUB, 0b11101111);

    if(i2c_last_error()) {
        dprint("Unable to setup left side!\n");
    }else {
        dprint("Left side OK!\n");
    } 
    
    //2nd device 
    i2c_write8(I2CL_ADDRESS, IODIRA, HIGH);
    i2c_write8(I2CL_ADDRESS, IODIRB, HIGH);
    //seems like A pull ups also needed
    i2c_write8(I2CL_ADDRESS, GPPUA, HIGH);
    //set B pull ups ON 0b11101111
    i2c_write8(I2CL_ADDRESS, GPPUB, 0b11101111);
    if(i2c_last_error()) {
        dprint("Unable to setup right side!\n");
    }else {
        dprint("Left right OK!\n");
    }
}  

bool isI2C_initialized() {
    return i2c_initialized;
}

uint8_t i2c_read8(uint8_t addr, uint8_t reg) {
    uint8_t data = 0;
    last_err = i2c_start(addr, I2C_TIMEOUT); if(last_err) goto end;
    last_err = i2c_readReg(addr, reg, &data, sizeof(data), I2C_TIMEOUT); if(last_err) goto end;    
    end:
        i2c_stop();
    return ~data;

}

void i2c_write8(uint8_t addr, uint8_t reg, uint8_t data) {
    last_err = i2c_start(addr, I2C_TIMEOUT); if(last_err) goto end;
    last_err = i2c_writeReg(addr, reg, &data, sizeof(data), I2C_TIMEOUT); if(last_err) goto end;
    end:
        i2c_stop();
}

void i2c_select_row(uint8_t row_index) {
    uint8_t row_mask = ~(1 << row_index);
    i2c_write8(I2CR_ADDRESS, GPIOA, row_mask);
}

void i2c_select_row_on(uint8_t addr, uint8_t row_index) {
    uint8_t row_mask = ~(1 << row_index);
    i2c_write8(addr, GPIOA, row_mask);
} 

i2c_status_t i2c_last_error(void) {
    return last_err;
}

report_mouse_t pointing_device_task_user(report_mouse_t report) {   

    //scrollv
    if(current_pseudolayer==BALL_SCROLL) {
        if(report.y < 0) 
            scrollv--;
        if(report.y > 0)
            scrollv++;  

        if(report.x < 0)          
            scrollh--;
        if(report.x > 0)
            scrollh++;

        if((scrollv > SCROLLV_TRESHOLD) || (scrollv < -SCROLLV_TRESHOLD)) {
            if(scrollv > 0)
                report.v = -1;
            if(scrollv < 0)
                report.v = 1;

            scrollv = 0;
            scrollh = 0;
        }

        if((scrollh > SCROLLH_TRESHOLD) || (scrollh < -SCROLLH_TRESHOLD)) {
            if(scrollh > 0)
                report.h = 1;
            if(scrollh < 0)
                report.h = -1;

            scrollh = 0;
            scrollv = 0;
        }
       
        report.x = 0;
        report.y = 0;
        
    }

    //volume
    if(current_pseudolayer == BALL_VOLUME) {
        if(report.y < 0) 
            scrollv--;
        if(report.y > 0)
            scrollv++;
        
        if(scrollv > VOLUME_TRESHOLD) {
            tap_code(KC_VOLD);
            scrollv = 0;
        }

        if(scrollv < -VOLUME_TRESHOLD) {
            tap_code(KC_VOLU);
            scrollv  = 0;
        }
        report.x = 0;
        report.y = 0;                                                   
    }

    return report;
}

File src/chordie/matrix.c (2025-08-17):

#include <stdint.h>
#include <stdbool.h>
#include "wait.h"
#include "print.h"
#include "debug.h"
#include "util.h"
#include "matrix.h"
#include "debounce.h"
#include "quantum.h"

#include QMK_KEYBOARD_H

#if (MATRIX_COLS <= 8)
#    define print_matrix_header() print("\nr/c 01234567\n")
#    define print_matrix_row(row) print_bin_reverse8(matrix_get_row(row))
#    define matrix_bitpop(i) bitpop(matrix[i])
#    define ROW_SHIFTER ((uint8_t)1)
#elif (MATRIX_COLS <= 16)
#    define print_matrix_header() print("\nr/c 0123456789ABCDEF\n")
#    define print_matrix_row(row) print_bin_reverse16(matrix_get_row(row))
#    define matrix_bitpop(i) bitpop16(matrix[i])
#    define ROW_SHIFTER ((uint16_t)1)
#elif (MATRIX_COLS <= 32)
#    define print_matrix_header() print("\nr/c 0123456789ABCDEF0123456789ABCDEF\n")
#    define print_matrix_row(row) print_bin_reverse32(matrix_get_row(row))
#    define matrix_bitpop(i) bitpop32(matrix[i])
#    define ROW_SHIFTER ((uint32_t)1)
#endif

#ifdef MATRIX_MASKED
extern const matrix_row_t matrix_mask[];
#endif

/* matrix state(1:on, 0:off) */
static matrix_row_t raw_matrix[MATRIX_ROWS];  // raw values
static matrix_row_t matrix[MATRIX_ROWS];      // debounced values

//__attribute__((weak)) void matrix_init_quantum(void) { matrix_init_kb(); }
//__attribute__((weak)) void matrix_scan_quantum(void) { matrix_scan_kb(); }
__attribute__((weak)) void matrix_init_kb(void) { matrix_init_user(); }
__attribute__((weak)) void matrix_scan_kb(void) { matrix_scan_user(); }
__attribute__((weak)) void matrix_init_user(void) {}
__attribute__((weak)) void matrix_scan_user(void) {}
//__attribute__((weak)) void matrix_init_kb(void) {}

inline uint8_t matrix_rows(void) { return MATRIX_ROWS; }
inline uint8_t matrix_cols(void) { return MATRIX_COLS; }

#define ENC_RES 4
#define ENC_UP ((uint32_t) 1 )
#define ENC_DOWN (ENC_UP << 1) 
#define IR_STATE 0x10

int8_t enc_state = 0;
int8_t enc_count = 0;
int8_t enc_states [] = {0, -1, 1, 0, 1, 0, 0, -1, -1, 0, 0, 1, 0, 1, -1, 0};

/* HERE STARTS IMPLEMENTATION OF CUSTOM MATRIX HANDLING */
matrix_row_t matrix_get_row(uint8_t row) {
    // TODO: return the requested row data
    return matrix[row];
}

void matrix_power_up() {
    print("matrix.c->matrix_power_up()");
}

void matrix_power_down() {
    print("matrix.c->matrix_power_down()");
}

void matrix_print(void) {
    print_matrix_header();

    for (uint8_t row = 0; row < MATRIX_ROWS; row++) {
        print_hex8(row);
        print(": ");
        print_matrix_row(row);
        print("\n");
    }
}

void matrix_init(void) {
    // TODO: initialize hardware and global matrix state here
    i2c_initialize();
    for(uint8_t i = 0; i < MATRIX_ROWS; i++) {
        raw_matrix[i] = 0;
        matrix[i] = 0;
    }
   
    // Unless hardware debouncing - Init the configured debounce routine
    debounce_init(MATRIX_ROWS);

    // This *must* be called for correct keyboard behavior
    matrix_init_user();
}



uint8_t matrix_scan(void) {
    bool changed = false;
    uint8_t expander_data = 0;
    matrix_row_t current_row = 0;
    
    for(uint8_t i = 0; i < MATRIX_ROWS; i++) {
        //Read keys from L
        expander_data = i2c_read8(I2CL_ADDRESS, GPIOA);  

        if(i2c_last_error()) {
            dprint("Right side connection error!\n");
            i2c_initialize();
            current_row |= 0;
        }else {
            current_row |= expander_data;
        }
        current_row <<= 1;

        //Read bank B from L      
        expander_data = i2c_read8(I2CL_ADDRESS, GPIOB);

        if(i2c_last_error()) {
            dprint("Left side connection error!\n");
            i2c_initialize();
        }
        
        //extract encoder switch state 
        if(expander_data & 0x80)   
            current_row |= 1;        
        current_row <<= 1;

        //extract LIR state 
        if(expander_data & IR_STATE) {
            current_row |= 1;         
        
        }

        current_row <<= 8;
        
        //extract encoder A/B state
        expander_data &= 0x60;        
        expander_data >>= 5;        
        enc_count <<= 2;
        enc_count |= expander_data;
        enc_count &= 0xF;        
        enc_state += enc_states[enc_count];       
        
        //Read keys from R
        expander_data = i2c_read8(I2CR_ADDRESS, GPIOA);        
        if(i2c_last_error()) {
            dprint("Right side connection error!\n");
            i2c_initialize();
            current_row |= 0;
        }else {
            current_row |= expander_data;
        }
       
        //Read encoder from R       
        expander_data = i2c_read8(I2CR_ADDRESS, GPIOB);  

        if(i2c_last_error()) {
            dprint("Right side connection error!\n");
            i2c_initialize();
        } 
     
        //extract RIR from R
        current_row <<= 1;
        if(expander_data & IR_STATE)
            current_row |= 1;              

        current_row <<= 2;

        if(current_row != raw_matrix[i]) {
            raw_matrix[i] = current_row;
            changed = true;
        } 
        current_row = 0;
    }    

    debounce(raw_matrix, matrix, MATRIX_ROWS, changed);
    
    if (enc_state <= -ENC_RES ) {
        matrix[0] |= ENC_DOWN;
        enc_state = 0;
    }else {
        matrix[0] &= ~ENC_DOWN;
    }

    if (enc_state >= ENC_RES) {
        matrix[0] |= ENC_UP;
        enc_state = 0;
    }else {
        matrix[0] &= ~ENC_UP;
    }        


    matrix_scan_user();
    
    return changed;
}

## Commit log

2021-08-31 Improved top/bottom
    + top with raised thumb
    + bottom angled 15 deg w/o trackball
    + bottom angled 10 deg w/o trackball
    [right_bottom_10deg.stl, right_bottom_10deg_with_trackball_holder.stl, right_bottom_15deg.stl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]
2021-08-31 Typo for stl part
    [right_raised_thumb.stl]
2021-10-24 Added PMW3360
    + PMW3360 sensor support
    + disabled some of QMK features to release memory
2022-05-07 Updated due to QMK breaking changes
    New matrix scanning routine
    Use of QMK built in sensor handling
2023-03-09 Chordie V2
    [audiojack_lock.stl, bottom_left.stl, bottom_right.stl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]
2023-03-17 minor changes around ir sensor
    [chordie.scad]
2023-06-26 Minor update
    - change to wire canals
    - added default STLs for the top part
    [bottom_right.stl, chordie.scad, config.scad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]
2024-01-21 Improvemets
    - better trackball
    - bearing trap
    - increased sensor CPI
    [bearing_trap.stl]
2025-08-13 fix compilation errors for the new QMK version
    [matrix.c]
2025-08-17 Update README.md
    - updated BOM for bearings
    - new PMW3360 sensor from Aliexpress
